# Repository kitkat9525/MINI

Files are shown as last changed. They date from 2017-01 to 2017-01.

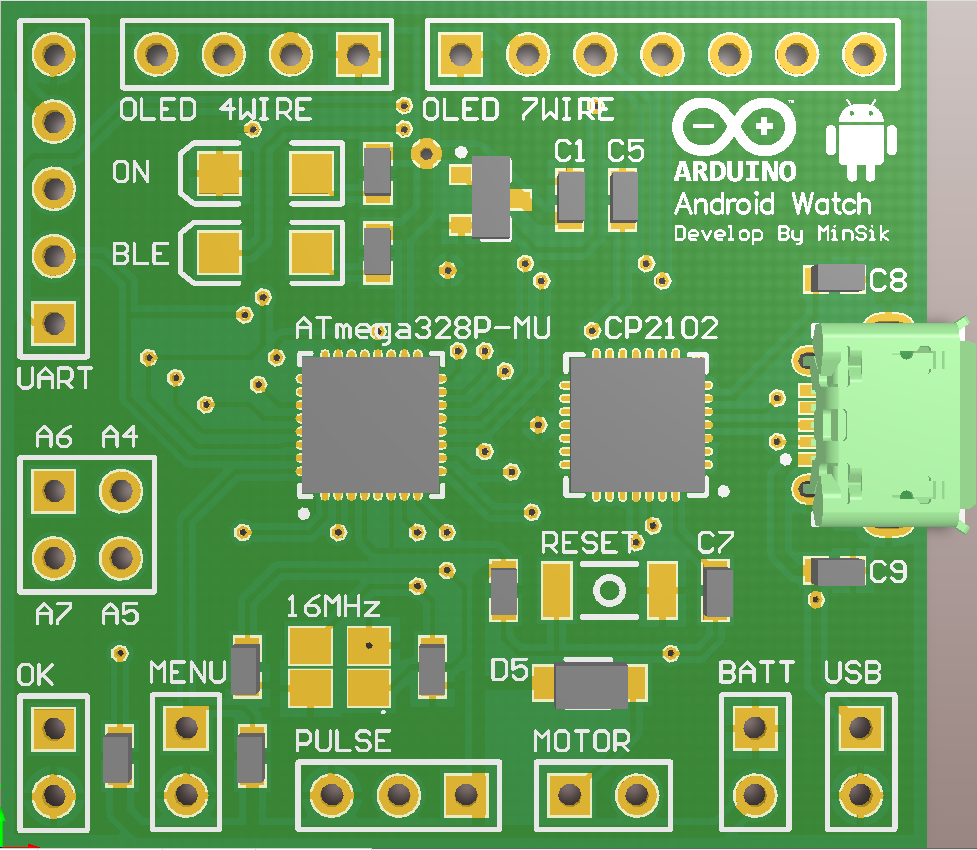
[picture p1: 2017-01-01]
PCBArtwork/PCB_Top_Layer.png

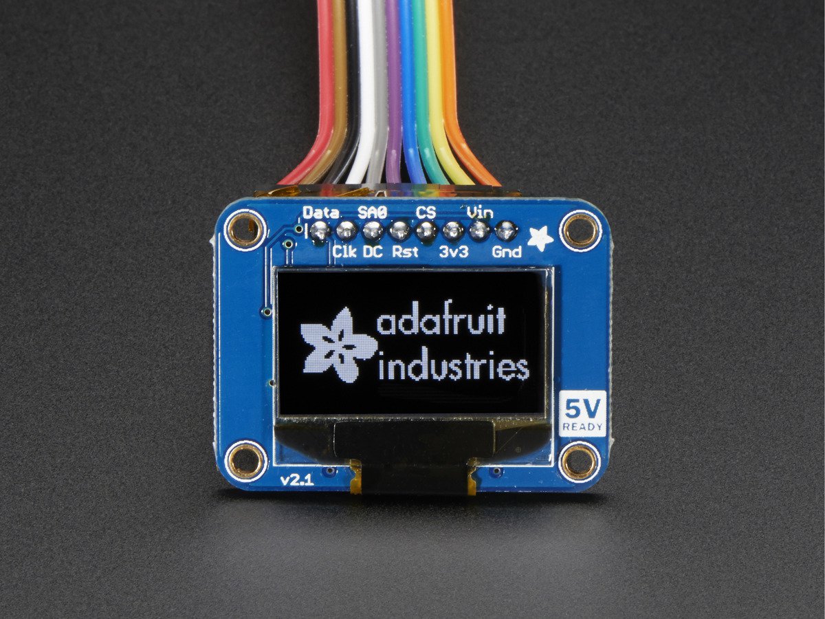
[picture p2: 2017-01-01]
Reference Circuit/Adafruit SSD1306 0.96 Inch OLED.jpg

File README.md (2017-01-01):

# MINI - Arduino Smart Watch with Android

-----

# PART LIST

## Arduino Mini Pro
https://store.arduino.cc/usa/arduino-mini-05


## Adafruit SSD1306 0.96 inch OLED
https://www.adafruit.com/product/326


## HM-10 + JDY-08 Bluetooth LE Module
https://forum.arduino.cc/index.php?topic=432074.0


-----
# Arduino

## Function
* Bluetooth LE Communication To Android Application
* Analog/Digital Clock
* Check SMS Message, Phone Call
* Sleep/Wake Mode (OLED Control for Battery Efficiency)  

-----

# Android
Use Bluetooth LE, BroadcastReceive for SMS, Phone Call

-----

# PCB Artwork (Altium Designer)

* Working with Altium Designer 17
* 35mm x 32mm 2 Layer

## Schematic


## PCB Top Layer


## PCB Bottom Layer


## PCB 3D View


-----

# Reference
https://www.arduino.cc/  
http://www.altium.com/

-----

**Copyright for MinSik.Kim**

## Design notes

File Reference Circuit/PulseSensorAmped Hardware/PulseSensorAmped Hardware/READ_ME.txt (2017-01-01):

These files were created in Design Spark Open Source Schematic Layout Software 
http://www.designspark.com/
You will need to copy the contents of DesignSparkLibraryFiles into the default Library that Design Spark uses. Normally something like Documents\DesignSpark PCB\Library
This is the only way you will be able to use or modify the APDS-9008 part or the reverse mount LED part.

CONTRIBUTORS BACKTRACK AND NOTIFICATION

joel@joelmurphy.net
yury.gitman@gmail.com

Licensed under the TAPR Open Hardware License (www.tapr.org/OHL)

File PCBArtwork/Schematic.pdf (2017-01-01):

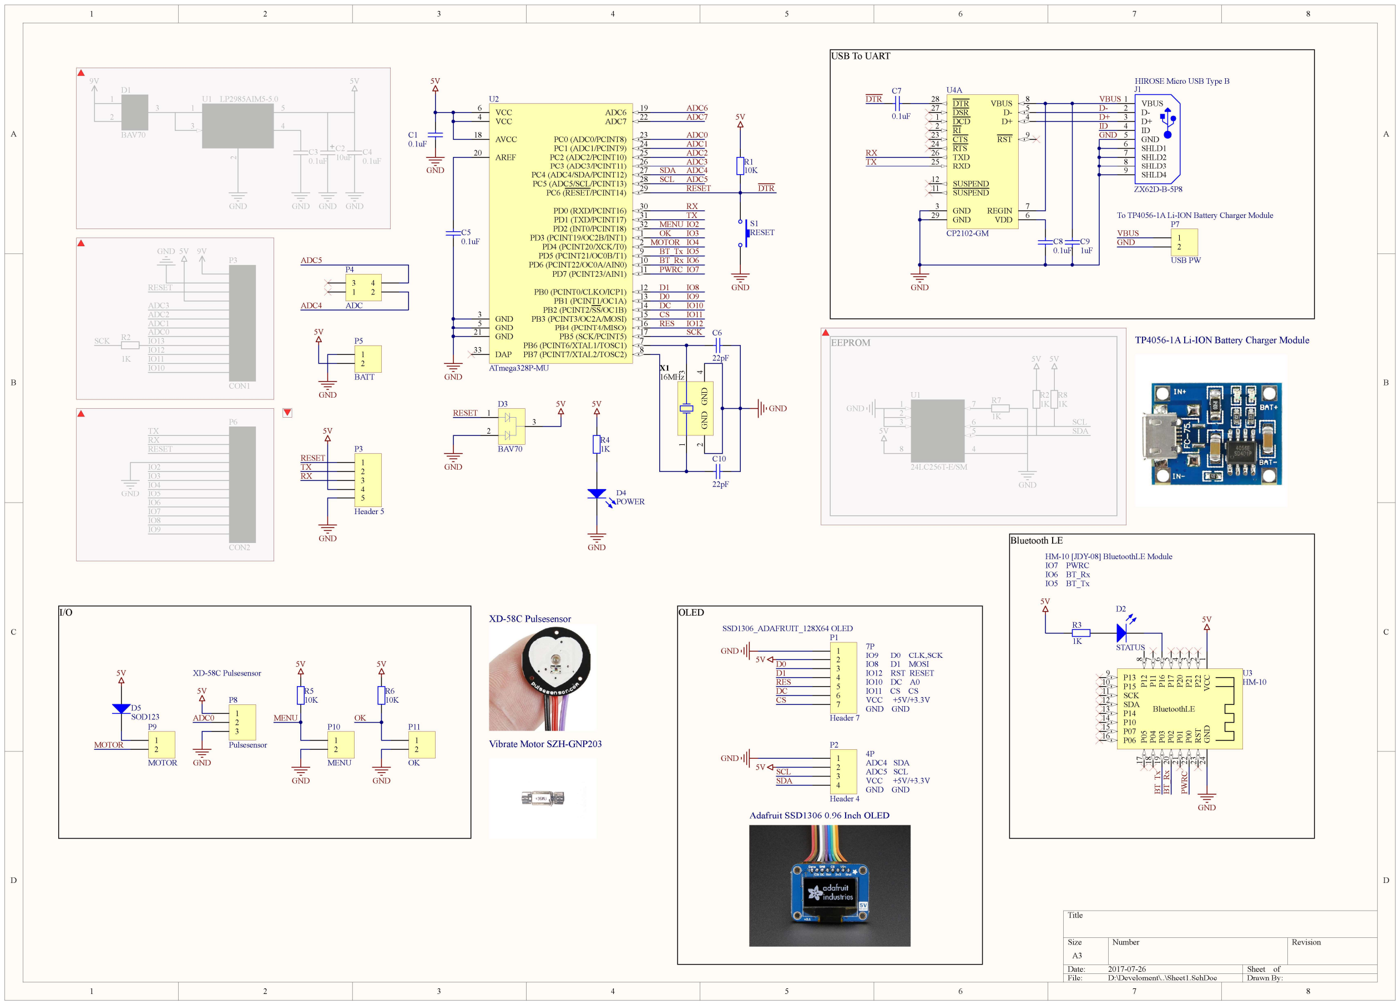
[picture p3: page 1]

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
Title

Size | Number | Revision
A3
Date: | 2017-07-26 | Sheet of
File: | D:\Develoment\..\Sheet1.SchDoc | Drawn By:
PC6 (RESET/PCINT14) | 29
PD0 (RXD/PCINT16) | 30
PD1 (TXD/PCINT17) | 31
PD2 (INT0/PCINT18) | 32
PD4 (PCINT20/XCK/T0) | 2

VCC 6

GND 5

PB6 (PCINT6/XTAL1/TOSC1) | 7
PB7 (PCINT7/XTAL2/TOSC2) | 8
PD5 (PCINT21/OC0B/T1) | 9
PD6 (PCINT22/OC0A/AIN0) | 10
PD7 (PCINT23/AIN1) | 11
PB0 (PCINT0/CLKO/ICP1) | 12
PB1 (PCINT1/OC1A) | 13
PB2 (PCINT2/SS/OC1B) | 14
PB3 (PCINT3/OC2A/MOSI) | 15
PB4 (PCINT4/MISO) | 16
PB5 (SCK/PCINT5) | 17

AVCC 18

AREF 20

GND 21

PC0 (ADC0/PCINT8) | 23
PC1 (ADC1/PCINT9) | 24
PC2 (ADC2/PCINT10) | 25
PC3 (ADC3/PCINT11) | 26
PC4 (ADC4/SDA/PCINT12) | 27
PC5 (ADC5/SCL/PCINT13) | 28

GND 3

VCC 4

ADC6 | 19
ADC7 | 22

DAP 33

PD3 (PCINT19/OC2B/INT1) 1

U2

ATmega328P-MU

IN 1 | OUT | 5 2
CBYP | 4 ON/OFF 3
GND

U1 LP2985AIM5-5.0

1

2

3

D3

BAV70

1

2

3

D1

BAV70

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
CON2

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
CON1

1
2

P5

BATT

9V

GND | GND 0.1uF

C3
0.1uF

C4 10uF

C2

GND GND

5V

GND 9V

RESET

5V

ADC3
ADC2
ADC1
ADC0
IO13
IO12
IO11
IO10

1K

R2 SCK

TX
RX
RESET

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
ADC5

ADC4

5V

GND

GND

RESET

5V 5V

1K

R4

D4
POWER

GND

ADC6
ADC7

ADC0
ADC1
ADC2
ADC3
ADC4
ADC5

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
IO10
IO11
IO12
SCK

5V

0.1uF

C1

GND

GND

0.1uF

C5

S1
RESET

GND

5V

10K

R1

22pF

C6

GND 1 3 GND

## 2 GND

4

X1
16MHz

SSD1306_ADAFRUIT_128X64 OLED

IO9 | D0 CLK,SCK
IO8 | D1 MOSI
IO12 RST RESET
IO10 DC A0
IO11 CS CS
VCC +5V/+3.3V
GND GND

ADC4 SDA
ADC5 SCL
VCC +5V/+3.3V
GND GND

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
Header 7

1
2
3
4

P2

Header 4

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
5V SCL
SDA

D0

D1

RES

DC
CS

SCL

SDA | P⁰⁵ 17 P⁰⁴ 18 P⁰³ 19 P⁰² 20 P⁰¹ 21 P⁰⁰ 22 RST 23 GND 24 P¹²

### 8 P11

### 7 P16

### 6 P17

### 5 P20

### 4 P21

### 3 P22

### 2 VCC

1
P13 9
P15 10
SCK 11
SDA 12
P14 13
P10 14
P07 15
P06 16

BluetoothLE

U3
HM-10

5V

GND BT_Tx BT_Rx PWRC

5V

1K

R3

D2

STATUS

PWRC

BT_Rx

BT_Tx

HM-10 [JDY-08] BluetoothLE Module IO7 PWRC
IO6 BT_Rx
IO5 BT_Tx

1
2
3

P8

Pulsesensor

5V

GND

ADC0

XD-58C Pulsesensor

5V

10K

R6

5V

10K

R5

MOTOR

OK

MENU

MENU | OK

1
2

P9

MOTOR

5V

MOTOR

D5
SOD123

RESET

DCD 1
RI 2

GND 3

D+ | 4
D- | 5
VDD | 6
REGIN | 7
VBUS | 8
RST | 9
SUSPEND 11 | SUSPEND 12

CTS 23
RTS 24
RXD 25 | TXD 26
DSR 27 | DTR 28

GND 29

U4A

CP2102-GM

SHLD4 9

SHLD3 8

SHLD2 7

SHLD1 6

VBUS 1
D- 2
D+ 3
ID 4
GND 5

J1

ZX62D-B-5P8

HIROSE Micro USB Type B

I/O

D-D+
ID

1uF

C9
0.1uF

C8

GND

0.1uF

C7

DTR

DTR

### USB To UART

1
2

P7

USB PW

VBUS

GND

VBUS
GND

To TP4056-1A Li-ION Battery Charger Module

### OLED

### Bluetooth LE

### TP4056-1A Li-ION Battery Charger Module

### XD-58C Pulsesensor

### Vibrate Motor SZH-GNP203

### Adafruit SSD1306 0.96 Inch OLED

22pF

C10

1
2

P10

MENU

1
2

P11

OK

GND | GND

1
2
3
4
5

P3

Header 5

GND

5V

RESET
TX
RX

A0 1

SDA 5

A2 3

A1 2 | WP | 7
VSS | 4
SCL | 6

VCC 8

U1

24LC256T-E/SM

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
### EEPROM

RX
TX

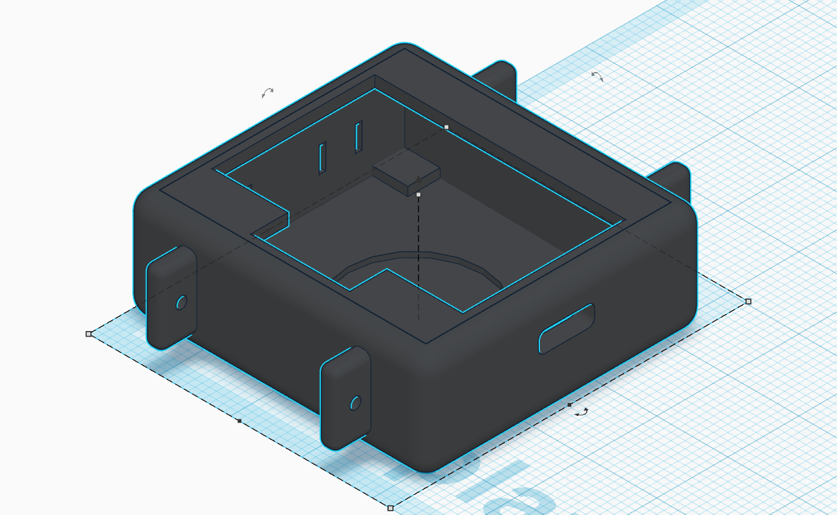
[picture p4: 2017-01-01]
3D Modeling/Modeling3.png

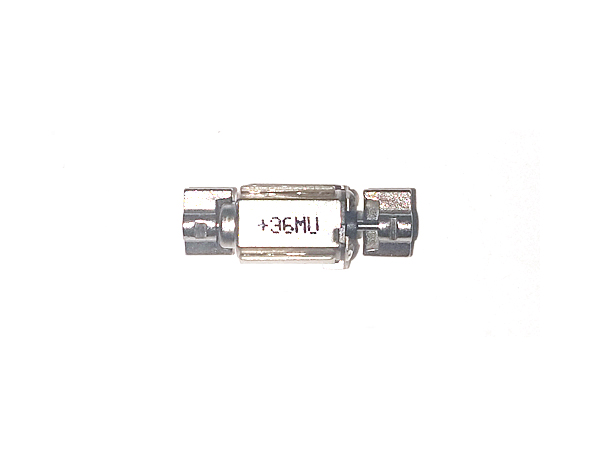
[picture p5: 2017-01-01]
Reference Circuit/SZH-GNP203.jpg

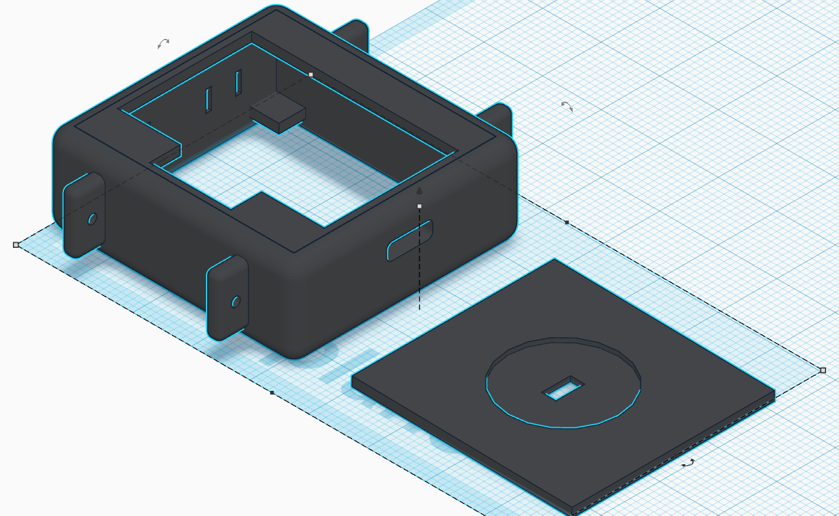
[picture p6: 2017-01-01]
3D Modeling/Modeling.png

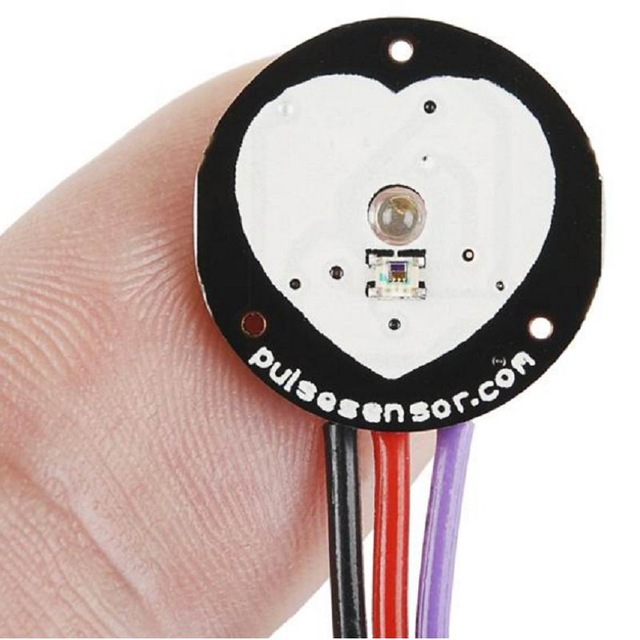
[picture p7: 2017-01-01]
Reference Circuit/XD-58C-Pulsesensor.jpg

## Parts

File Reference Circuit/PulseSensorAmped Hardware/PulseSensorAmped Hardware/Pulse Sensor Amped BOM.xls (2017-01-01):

Component | BoardRef | Value | Desc | Qty | Mfr | Package | Datasheet Link
APDS-9008 | U1 |  | Sensor | 1 | Avago | SMT | http://www.avagotech.com/docs/AV02-1169EN
MCP6001 | U2 |  | Op Amp |  |  |  | http://ww1.microchip.com/downloads/en/devicedoc/21733j.pdf
RevMntLED | D1 |  | Reverse Mount LED | 1 | Kingbright | Reverse Mount SMT | http://www.kingbrightusa.com/images/catalog/SPEC/AM2520ZGC09.pdf
Schottkey | D2 |  | Powerline Diode |  | Bourns | SMT0603 | http://www.bourns.com/data/global/pdfs/SBCD0603_1005.pdf
CAP 4.7uF 0603 | C1,C2,C3 | 4.7uF | Capacitor, Surface Mount Multi-Layer Ceramic | 1 | Various | SMT0603
CAP 0.1uF 0603 | C4,C5 | 2.2uF | Capacitor, Surface Mount Multi-Layer Ceramic | 1 | Various | SMT0603
R 470 0603 | R1 | 470K | SMT Resistor | 1 | Various | SMT0603
R 100 0603 | R2 | 12K | SMT Resistor | 1 | Various | SMT0603
R 13K 0603 | R3,R4 | 100K | SMT Resistor | 2 | Various | SMT0603
R 13K 0603 | R5 | 10K | SMT Resistor | 1 | Various | SMT0603
R 13K 0603 | R6 | 3.3M | SMT Resistor | 1 | Various | SMT0603

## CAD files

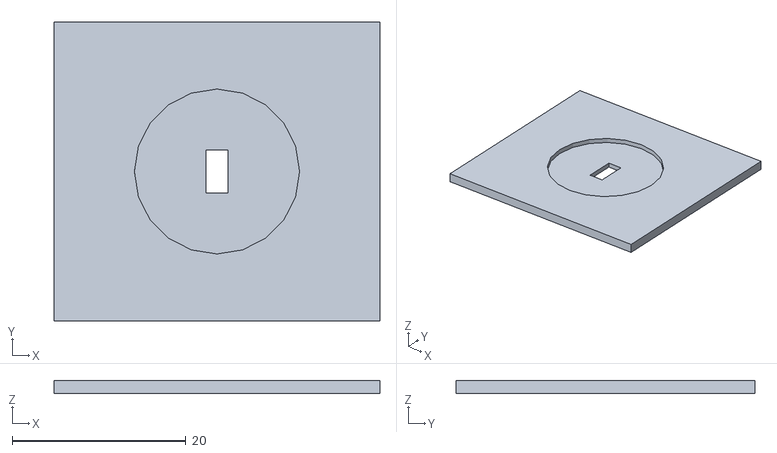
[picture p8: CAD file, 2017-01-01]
3D Modeling/model+plate.stl
37.5 x 34.4 x 1.50

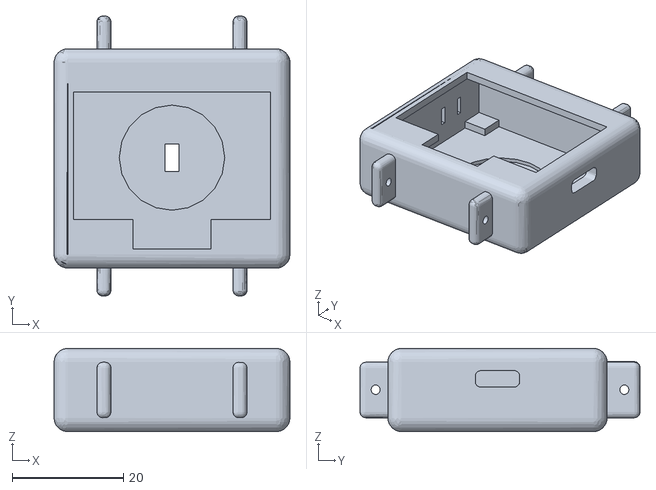
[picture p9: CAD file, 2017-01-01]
3D Modeling/uni.stl
42.5 x 50.4 x 15.0

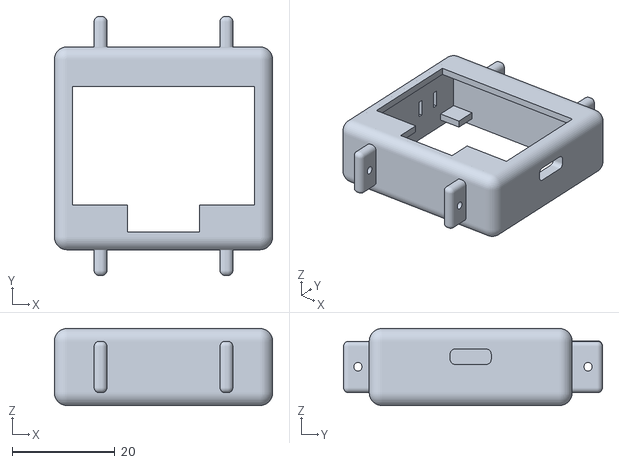
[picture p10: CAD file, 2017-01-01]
3D Modeling/model.stl
42.5 x 50.4 x 15.0

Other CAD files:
3D Modeling/plate.stl

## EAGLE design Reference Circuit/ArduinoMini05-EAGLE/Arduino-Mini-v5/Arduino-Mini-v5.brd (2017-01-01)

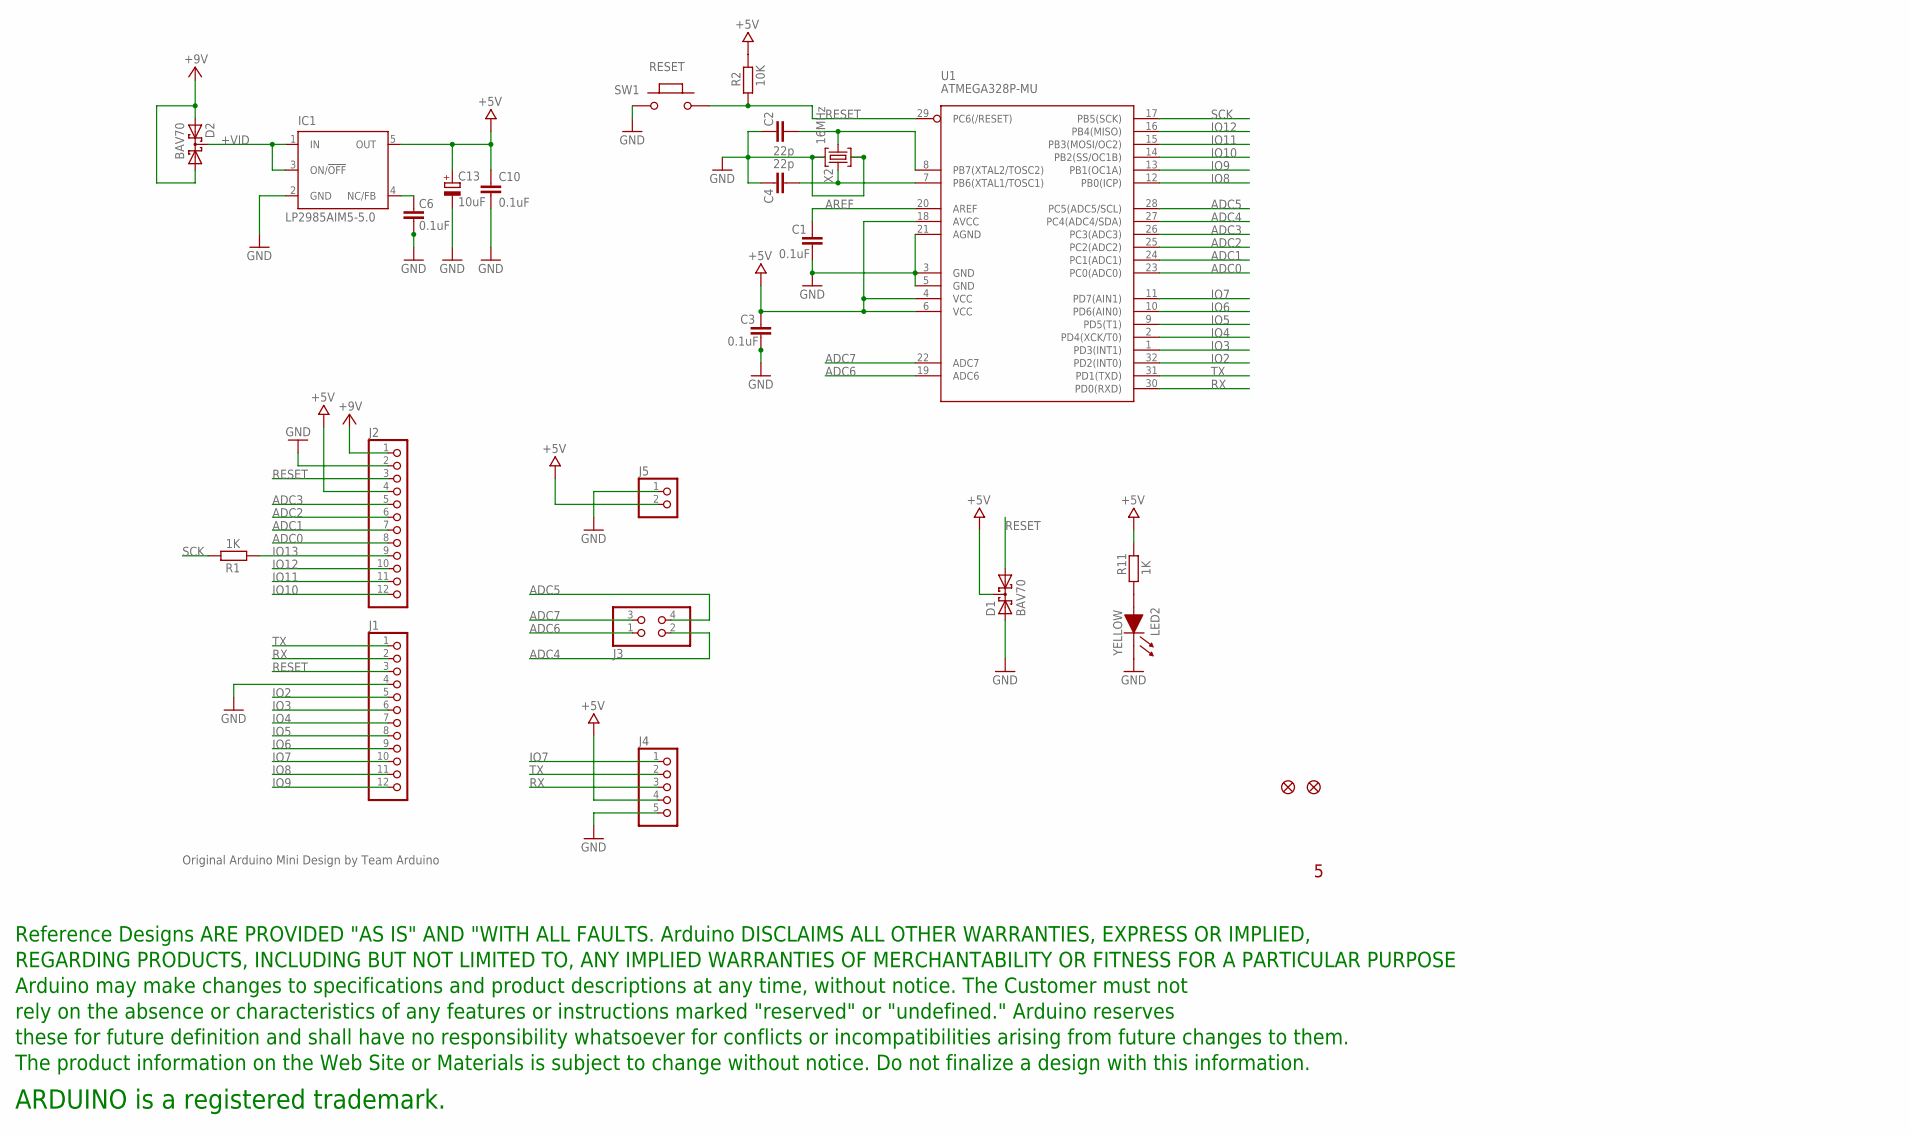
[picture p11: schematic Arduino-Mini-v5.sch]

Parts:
C1, C3, C6, C10: 0.1uF; C0603-ROUND
C2, C4: 22p; C0603-ROUND
C13: 10uF; SMC_B
D1, D2: BAV70; SOT23
IC1: LP2985AIM5-5.0; SOT23-DBV
J1, J2: PINHD-1X12; 1X12
J3: PINHD-2X2; 2X02
J4: PINHD-1X5; 1X5
J5: PINHD-1X2; 1X2
LED2: YELLOW; SMD_LED0805
R1, R11: 1K; R0603-ROUND
R2: 10K; R0603-ROUND
SW1: RESET; SMD_157SW
U1: ATMEGA328P-MU; MLF32-M1-A
U$2, U$4: FIDUCIAL1X2; FIDUCIAL-1X2
U$11: DISCLAIMER
X2: 16MHz; CRYSTAL-3.2-2.5

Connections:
+5V: C3.2, C10.1, C13.+, D1.3 (C), IC1.5 (OUT), J2.4, J4.4, J5.2, R2.2, R11.2, U1.4 (VCC), U1.6 (VCC), U1.18 (AVCC)
+VID: D2.3 (C), IC1.1 (IN), IC1.3 (ON/!OFF)
ADC0: J2.8, U1.23 (PC0(ADC0))
ADC1: J2.7, U1.24 (PC1(ADC1))
ADC2: J2.6, U1.25 (PC2(ADC2))
ADC3: J2.5, U1.26 (PC3(ADC3))
ADC4: J3.2, U1.27 (PC4(ADC4/SDA))
ADC5: J3.4, U1.28 (PC5(ADC5/SCL))
ADC6: J3.1, U1.19 (ADC6)
ADC7: J3.3, U1.22 (ADC7)
AREF: C1.2, U1.20 (AREF)
GND: C1.1, C2.2, C3.1, C4.2, C6.1, C10.2, C13.-, D1.1 (A1), IC1.2 (GND), J1.4, J2.2, J4.5, J5.1, LED2.1 (CA), SW1.1, U1.3 (GND), U1.5 (GND), U1.21 (AGND), X2.2 (GND), X2.4 (GND)
IO2: J1.5, U1.32 (PD2(INT0))
IO3: J1.6, U1.1 (PD3(INT1))
IO4: J1.7, U1.2 (PD4(XCK/T0))
IO5: J1.8, U1.9 (PD5(T1))
IO6: J1.9, U1.10 (PD6(AIN0))
IO7: J1.10, J4.1, U1.11 (PD7(AIN1))
IO8: J1.11, U1.12 (PB0(ICP))
IO9: J1.12, U1.13 (PB1(OC1A))
IO10: J2.12, U1.14 (PB2(SS/OC1B))
IO11: J2.11, U1.15 (PB3(MOSI/OC2))
IO12: J2.10, U1.16 (PB4(MISO))
IO13: J2.9, R1.1
unnamed: C4.1, U1.7 (PB6(XTAL1/TOSC1)), X2.1 (C1)
unnamed: C2.1, U1.8 (PB7(XTAL2/TOSC2)), X2.3 (C2)
unnamed: C6.2, IC1.4 (NC/FB)
unnamed: LED2.2 (AN), R11.1
RESET: D1.2 (A2), J1.3, J2.3, R2.1, SW1.2, U1.29 (PC6(/RESET))
RX: J1.2, J4.3, U1.30 (PD0(RXD))
SCK: R1.2, U1.17 (PB5(SCK))
TX: J1.1, J4.2, U1.31 (PD1(TXD))
VCC: D2.1 (A1), D2.2 (A2), J2.1

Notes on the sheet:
Original Arduino Mini Design by Team Arduino

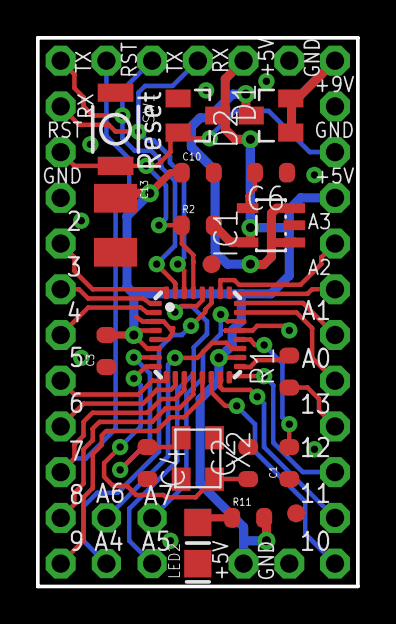
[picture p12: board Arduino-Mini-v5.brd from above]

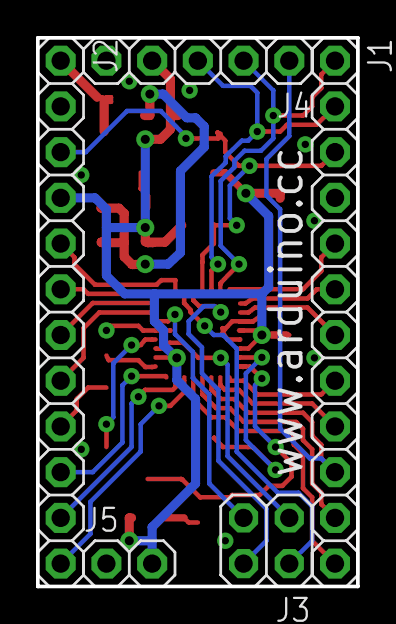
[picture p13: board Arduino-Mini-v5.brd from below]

Board: 2 copper layers, 17.8 x 30.5 mm, 25 parts (5 on the bottom side), 33 nets.

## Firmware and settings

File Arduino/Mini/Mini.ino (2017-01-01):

/*
 *  Circuit
 *  SSD1306_ADAFRUIT_128X64 OLED
 *  D0    CLK,SCK
 *  D1    MOSI
 *  RST   RESET
 *  DC    A0
 *  CS    CS
 *  VCC   +5V   
 *  GND   GND
 *  
 *  HM-10 Bluetooth Low Energy Module 
 *  VDD   +3.3V
 *  GND   GND
 *  P00   PWRC
 *  P01   Rx   
 *  P03   Tx
 */

#include <SoftwareSerial.h> // UART
#include <SPI.h>
#include <TimeLib.h>
#include <string.h>
#include <math.h>

#include "U8glib.h" // Organic Liquid Crystal Display Library
#include "bitmap.h"

#define BLE_PWRC 7 // 8  // P00 8
#define BLE_Rx 5 // 6  // P03 7
#define BLE_Tx 6 // 7  // P02 6

// Standart Arduino UNO 
#define D0 10
#define D1  9
#define RST 13
#define A0 11
#define CS 12

/*
    Use Custom PCB Board
    #define D0 9
    #define D1  8
    #define RST 12
    #define A0 10
    #define CS 11
*/

#define MODE_DEFAULT 0
#define MODE_INIT 1

#define MOTOR 4
#define SW 3

SoftwareSerial BluetoothLESerial(BLE_Rx, BLE_Tx); // Rx, Tx
// U8glib Constructor
// U8GLIB_SSD1306_128X64 u8g(D0, D1, CS, A0); // SW SPI Com: SCK = 10, MOSI = 9, CS = 12, A0(DC) = 11 
U8GLIB_SSD1306_ADAFRUIT_128X64 u8g(D0, D1, CS, A0); // SW SPI Com: SCK = 10, MOSI = 9, CS = 12, A0 = 11 
// U8GLIB_SSD1306_ADAFRUIT_128X64 u8g(CS, A0);    // HW SPI Com: CS = 10, A0 = 9 (Hardware Pins are  SCK = 13 and MOSI = 11)

int mode = 0;
int sleep = 0;

byte xPos = 64;
byte yPos = 32;
byte rad = 28;

void ArduinoInit(void);
void BluetoothLEInit(void);
void OLEDInit(void);

void BluetoothLE(void);

int callObserver(void);
int sleepObserver(void);

void syncTime(char* data);
void motor(void);

void drawString(int x, int y, char* str);
void drawImage(int x, int y, int cnt, int h, uint8_t* bitmap);

void drawSMSMessage(char* msg);
void drawIncomingCall(char* msg);
void drawAnalogClock(void);
void showTimePin(int center_x, int center_y, double pl1, double pl2, double pl3);

void setup() {
    // put your setup code here, to run once:
    ArduinoInit();
    BluetoothLEInit();
    OLEDInit();
    delay(2500);
}

void loop() {
    // put your main code here, to run repeatedly:
    sleepObserver();
    BluetoothLE();
    /*
     * Picture Loop
     * U8glib에는 "Picture Loop"라는 특별한 프로그래밍 구조
     * 그래픽 장치의 전체 그림은 그림 루프를 반복하여 그려집니다.
     * https://github.com/olikraus/u8glib/wiki/tpictureloop
     */
    if(mode == MODE_INIT){
        drawImage((128-64)/2, 0, 8, 64, Bluetooth);        
    } else {
        u8g.firstPage();  
        do { 
             drawAnalogClock();
        } while(u8g.nextPage()); 
    } 
}

void ArduinoInit(void){
    pinMode(MOTOR, OUTPUT);
    pinMode(SW, INPUT);
    
    digitalWrite(MOTOR, HIGH);
    mode = MODE_INIT;
}

void BluetoothLEInit(void){
    BluetoothLESerial.begin(115200); // Set 115200 Baud Rate
    Serial.begin(115200); // Set 115200 Baud Rate

    // BLE Start Message
    Serial.println("ATcommand");  // ATcommand Start
    delay(50);
}

void OLEDInit(void) {
    // flip screen, if required
    // u8g.setRot180();
    
    // set SPI backup if required
    u8g.setHardwareBackup(u8g_backup_avr_spi);
    
    // assign default color value
    if ( u8g.getMode() == U8G_MODE_R3G3B2 )
        u8g.setColorIndex(255);     // white
    
    else if ( u8g.getMode() == U8G_MODE_GRAY2BIT )
        u8g.setColorIndex(3);         // max intensity
    
    else if ( u8g.getMode() == U8G_MODE_BW )
        u8g.setColorIndex(1);         // pixel on
    
    else if ( u8g.getMode() == U8G_MODE_HICOLOR )
        u8g.setHiColorByRGB(255,255,255);
}

void BluetoothLE(void){
    if (BluetoothLESerial.available()) { // 시리얼 통신으로 BluetoothLESerial로 온 데이터가 있을 경우.
        char buf[50] = {0};
        byte len = BluetoothLESerial.readBytes(buf, 50);
        char data[len] = {0};
    
        for(int i=0; i<len+1; i++)
            data[i] = buf[i];
        
        Serial.print(data);
        
        if(sleep) {
            sleep = 0;
            u8g.sleepOff();
        }
        
        if(mode == MODE_INIT){
            syncTime(data);
            mode = MODE_DEFAULT;
        } else if(mode == MODE_DEFAULT){
            if(data[0] == '#') {
                drawIncomingCall(strtok(data, "#"));
            } else if(data[0] == '&') {
                drawString(0, 0, "Call End");
                delay(500);
            } else{
                drawSMSMessage(data);
            }
        }
    } else if (Serial.available()) { // 시리얼 통신으로 Serial로 온 데이터가 있을 경우.
        // BluetoothLESerial.write(Serial.read());
        char buf[50] = {0};
        byte len = Serial.readBytes(buf, 50);
        char data[len] = {0};
    
        for(int i=0; i<len+1; i++)
            data[i] = buf[i];
    }
}

int callObserver(void){
    if (BluetoothLESerial.available()) { // 시리얼 통신으로 BluetoothLESerial로 온 데이터가 있을 경우.
        char buf[50] = {0};
        byte len = BluetoothLESerial.readBytes(buf, 50);
        char data[len] = {0};
    
        for(int i=0; i<len+1; i++)
            data[i] = buf[i];
            
       if(data[0] == '&')
          return 0;
    } else { 
        return 1;
    }     
}

int sleepObserver(void){
    if(sleep)
        u8g.sleepOn();
    else 
        u8g.sleepOff();
        
    if(!digitalRead(SW)){
        if(!sleep) {
            sleep = 1;
            delay(500);
        } else {
            sleep = 0;
            delay(500);
        }
    } 
}

// Time Function
void syncTime(char* data){
    char *token;
    int arr[6];
    int i=0;
    /* the string pointed to by string is broken up into the tokens
    "a string", " of", " ", and "tokens" ; the null terminator (\0)
    is encountered and execution stops after the token "tokens" */
    token = strtok(data, ":");
    while (token != NULL){
        Serial.print(token);
        arr[i] = atoi(token), i++; 
        token = strtok(NULL, ":");
    }
    
    setTime(arr[3], arr[4], arr[5], arr[2], arr[1], arr[0]);
    // setTime(Hour, Min, Sec, Day, Month, Year);          
}

void motor(void){
    int cnt = 2;
    for(int i=0; i<2; i++){
        digitalWrite(MOTOR, LOW);
        delay(50);
        digitalWrite(MOTOR, HIGH);
        delay(50);
    }
}

// Draw Function
void drawString(int x, int y, char* str){
    // graphic commands to redraw the complete screen should be placed here  
    u8g.setFont(u8g_font_unifont);
    // u8g.setFont(u8g_font_osb21);
    u8g.drawStr(x, y, str);
}

void drawSMSMessage(char* msg){
    int i=0;
    motor();
    drawImage((128-64)/2, 0, 8, 64, SMS);        
    delay(2500);
    
    while(1){
        if(!digitalRead(SW))
            break;
        else if(i >= 200) // 10 sec Wait
            break;
            
        u8g.firstPage();  
        do {
            drawString(0, 10, "SMS Message");
            drawString(0, 25, msg);
        } while(u8g.nextPage());
        // rebuild the picture after some delay
        delay(50);
        i++;
    } 
}

void drawIncomingCall(char* msg){
    drawImage((128-64)/2, 0, 8, 64, PHONE);        
    delay(2500);
    while(callObserver()){
        motor();   
        u8g.firstPage();  
        do {
            drawString(0, 10, "Incoming Call");
            drawString(0, 25, msg);
        } while(u8g.nextPage());
        // rebuild the picture after some delay
        delay(50);
    }
}

void drawImage(int x, int y, int cnt, int h, uint8_t* bitmap){
    // void U8GLIB::drawBitmap(u8g_uint_t x, u8g_uint_t y, u8g_uint_t cnt, u8g_uint_t h, const uint8_t *bitmap) 
    // void U8GLIB::drawBitmapP(u8g_uint_t x, u8g_uint_t y, u8g_uint_t cnt, u8g_uint_t h, const u8g_pgm_uint8_t *bitmap)
    /*
     * u8g: u8g구조체의 포인터 (C 인터페이스 전용).
     * x: OLED Xpos (비트 맵의 왼쪽 위치).
     * y: OLED Ypos (비트 맵의 위쪽).
     * cnt: 가로 방향 비트 맵 배열의 바이트 수. 비트 맵 배열의 높이는 cnt*8.
     * h: 비트 맵 배열의 높이.
     */
    u8g.firstPage();  
    do { 
        u8g.drawBitmapP(x, y, cnt, h, bitmap);
    } while(u8g.nextPage());
    delay(50);
}

void drawAnalogClock(){
    // graphic commands to redraw the complete screen should be placed here  
    u8g.setFont(u8g_font_unifont);
    // CLOCK_STYLE_SIMPLE_ANALOG.
    u8g.drawCircle(xPos, yPos, rad);
    showTimePin(xPos, yPos, 0.1, 0.5, hour()*5 + (int)(minute()*5/60));
    showTimePin(xPos, yPos, 0.1, 0.65, minute());
    showTimePin(xPos, yPos, 0.1, 0.78, second());
}

// Calculate clock pin position
const double RAD = 3.141592/180;
const double LR = 89.99;
void showTimePin(int center_x, int center_y, double pl1, double pl2, double pl3){
    double x1, x2, y1, y2;
    x1 = xPos + (rad * pl1) * cos((6 * pl3 + LR) * RAD);
    y1 = yPos + (rad * pl1) * sin((6 * pl3 + LR) * RAD);
    x2 = xPos + (rad * pl2) * cos((6 * pl3 - LR) * RAD);
    y2 = yPos + (rad * pl2) * sin((6 * pl3 - LR) * RAD);
    
    u8g.drawLine((int)x1, (int)y1, (int)x2, (int)y2);
}
